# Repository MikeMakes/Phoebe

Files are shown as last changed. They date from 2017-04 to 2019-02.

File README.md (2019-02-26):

# Phoebe
I am Phoebe, an amphibian vehicle developed by students from the University of Seville.

The concept is a tele-operated airboat like vehicle with a raspberry pi as brain controled from a pc through Ad-Hoc wifi.

This was an one trimester class project that is alredy finished and abandoned but what you see is functional and there are somethings that even work well. 100% FREE SOFTWARE take whatever u want; if you do so, I would apreciatte a link to your project just for the sake of curiosity.

A full in detail doc (in spanish) can be found as doc.pdf.

# Adhoc

# Control

# Arducontrol

# All this is free

    Copyright (C) 2017
        Authors:
            * Miguel López Gil
            * Pelayo Gutiérrez Jiménez
            * Juan Sandubete López
            * Javier Ponce Chulani
            * Alvaro Morales Marquez
            * Bryan Kevin Condor Romero
            * Jose Manuel Salvador Vazquez

    This program is free software: you can redistribute it and/or modify
    it under the terms of the GNU General Public License as published by
    the Free Software Foundation, either version 3 of the License, or
    (at your option) any later version.

    This program is distributed in the hope that it will be useful,
    but WITHOUT ANY WARRANTY; without even the implied warranty of
    MERCHANTABILITY or FITNESS FOR A PARTICULAR PURPOSE.  See the
    GNU General Public License for more details.

    You should have received a copy of the GNU General Public License
    along with this program. If not, see <http://www.gnu.org/licenses/>.

# TODOs
* Finish readme
* Link doc.pdf

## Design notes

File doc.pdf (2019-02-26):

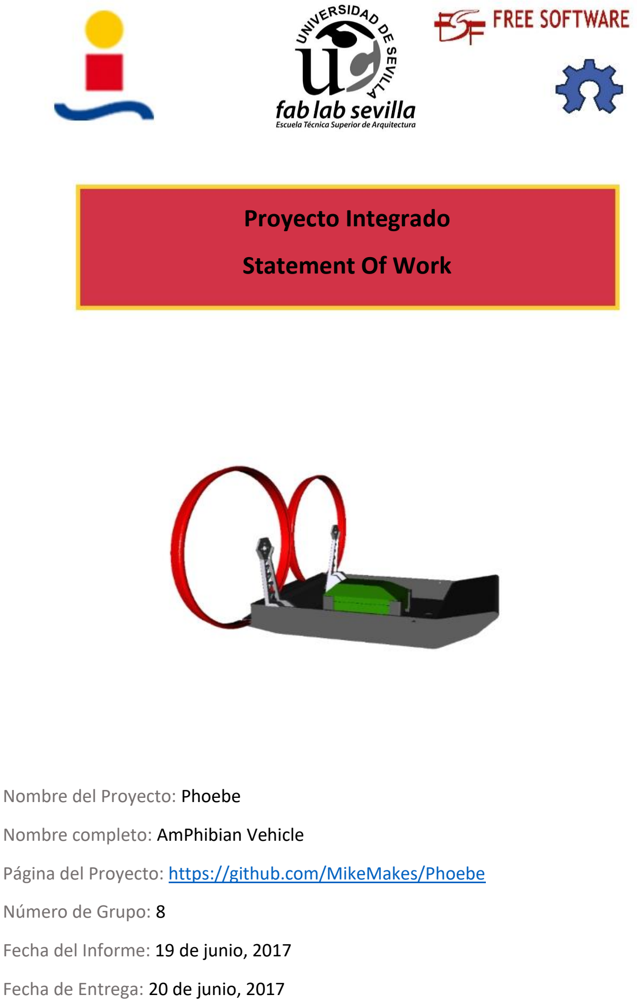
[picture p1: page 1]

Nombre del Proyecto: Phoebe

Nombre completo: AmPhibian Vehicle

Página del Proyecto: https://github.com/MikeMakes/Phoebe

Número de Grupo: 8

Fecha del Informe: 19 de junio, 2017

Fecha de Entrega: 20 de junio, 2017

## Proyecto Integrado

## Statement Of Work

## Índice

### Integrantes del Grupo

Bryan Kevin Cóndor Romero

Pelayo Gutiérrez Jiménez

Álvaro Morales Márquez

Javier Ponce Chulani

José Manuel Salvador Vázquez

Juan Sandubete López

3º GIERM

### 1. Introducción

El proyecto persigue desarrollar un vehículo radio-control anfibio multipropósito con retransmisión de vídeo en directo, a fin de expandir los conocimientos aplicados actualmente a UAVs (como son la electrónica de potencia, la ingeniería de control, la informática y otras) a otra clase de vehículos no tripulados poco estudiados hasta la fecha y proponerlo como solución a diferentes problemas.

Entre los sistemas que han sido desarrollados actualmente con la misma finalidad, se pueden encontrar diferentes proyectos que incluyen colchón aéreo; el conocido Hovercraft[1][2]
Aunque esto tiene claras ventajas sobre la fricción del vehículo con el terreno, supone incluir otro motor dedicado exclusivamente a generar dicho colchón de suspensión, que además de encarecer el precio del sistema, da lugar a una dependencia crucial entre la alimentación de dicho motor (y su correcto funcionamiento) y la integridad del sistema (que podría sumergirse en caso de no funcionar adecuadamente la suspensión aérea); por no contar con el hecho de que aumentaría considerablemente el consumo energético del vehículo, reduciendo la autonomía máxima alcanzable.

Como alternativa a la anterior opción, más cara y menos segura, se propone en el documento presente un vehículo anfibio en el que el colchón aéreo se sustituye por una barcaza estanca, para asegurar la flotabilidad del sistema. Una de las principales ventajas del diseño radica en la versatilidad del mismo; pues dicha superficie puede deslizar sin problemas por gran variedad de superficies, excluyendo, únicamente, superficies demasiado abrasivas como terrenos pedregosos.

Muchos son los posibles usos que se le pueden dar a este vehículo no tripulado. Algunas de las aplicaciones propuestas son:

- Supervisión de infraestructuras marítimas de difícil acceso o cuyo acceso conlleve peligro para las personas encargadas de su mantenimiento. Por ejemplo, supervisión del estado de la estructura inferior de un muelle o bien, la supervisión de cualquier tipo de estructuras situadas en zonas de aguas contaminadas[3]
- Vigilancia teleguiada de entornos nevados, pues la barcaza permite, primero, permanecer en estado de reposo durante más tiempo que un UAV tradicional, conservando energía, y segundo, la carencia de ruedas lo hace ideal para desplazarse por nieve.
- Visualización a distancia de zonas afectadas por inundaciones, preservando la seguridad del teleoperador. La naturaleza de la barcaza, permite que ésta se desplace, indistintamente, sobre terreno sólido, charcos o zonas inundadas. Además, la lluvia y el viento no son factores tan críticos como pudieran serlo para los UAV tradicionales.

### 2. Alcance

El sistema, como vehículo anfibio manejado por radio-control, debe ser capaz de desplazarse tanto por agua como por terreno sólido, pudiendo hacer la transición, al menos, de tierra al agua descendiendo una rampa de inclinación reducida. Además, transmitirá video por telemetría a una estación de monitorización y control; que dispone de un monitor donde se puede observar la visión proporcionada por el vehículo y envía las órdenes de control mediante comandos, a través de un Gamepad.

### 2.1 Memoria

El desarrollo del proyecto ha sido satisfactorio, no obstante, no pudieron alcanzarse todos los objetivos planteados.

La problemática comenzó la compra de los componentes. Al ser componentes caros, de aeromodelismo la mayoría de ellos, se optó por pedirlos de China y Taiwán, que los ofrecían a precios menores, aunque con mayor tardanza en la entrega.

Como consecuencia, en las dos primeras sesiones prácticas, sólo se pudo trabajar en el código que se pretendía emplear (Ad-hoc, TCP, streaming) y en la elaboración del circuito para la detección de agua; a la vez que se iba desarrollando la barcaza mediante diseño 3D.

Parte de los componentes llegaron, concretamente, los motores y las hélices; pero los controladores fueron pedidos incompatibles con los motores brushless empleados (pues eran para motores brushed); por lo que hubo que descambiarlos y se tardó más en recibir los nuevos controladores.

Para la cuarta sesión práctica ya se tenían tanto los controladores como los motores (además de parte de la estructura elaborada). Se pudieron probar los motores y controladores satisfactoriamente, aunque ya ahí se vio que no era fácil utilizar el protocolo de comunicación que emplean los controladores mediante la Raspberry.

En una de las sesiones prácticas que se hicieron adicionales (en un domicilio particular), se consideró que ya se podía probar el sistema completo, pues ya habían sido probados todos los subsistemas individualmente. Así pues, mientras se estaba procediendo con la calibración del segundo controlador, hubo un falló y en lugar de calibrarse, el controlador lo detectó como una activación. El fallo provocó una sobreintensidad que atravesó al controlador y lo quemó a tres días de la presentación final.

Como medida, se optó por emplear controladores de segunda mano, pero con mayor capacidad de control de corriente (pasando de los 10A a los 20A).

No obstante, los nuevos controladores no permitían la comunicación para los niveles de tensión maneja la Raspberry (3.4V respecto a los 5V necesarios). Por tanto, se pensó en diseñar una interfaz de comunicación entre la misma y los controladores.

Ésta se diseñó mediante dos transistores BJT en conexión Darlington, con una alimentación de 5V. Aunque por falta de tiempo (día previo a la presentación), se tuvo que optar, finalmente, por emplear como adaptador un Arduino en lugar de fabricar la placa de interfaz.

En los días siguientes a la presentación, se ha estado trabajando en la adaptación de la barcaza al medio acuoso. Con el fin de impermeabilizar la barcaza, se ha usado una resina de poliéster capaz de impregnar las piezas impresas en 3D. De este modo, se sellan las juntas y se consigue una mejor unión entre las diferentes secciones.

Además de la resina, para adquirir mayor robustez en toda la barcaza aplicamos una capa de fibra de vidrio en el casco, consiguiendo así una capa más de protección ante el rozamiento con el suelo.

Sin embargo, la fibra de vidrio ha creado burbujas en la capa de resina (imposibles de purgar en la práctica) por las que el agua puede fluir y alcanzar las capas más externas de la impresión 3D. Esto provoca unas pequeñas fugas en el casco que a largo plazo inundan la barcaza.

Por tanto, para el día de entrega de los resultados, se han tenido que abandonar los requisitos asociados a la desenvoltura del sistema en agua. Aunque algunos de las pruebas han podido ser realizadas (ver matriz de verificación), ninguna de las relacionadas al agua ha podido cumplirse satisfactoriamente.

No obstante, se ha conseguido (como se ve más fácilmente en la matriz de verificación) alcanzar objetivos que también fueron motivos de duda, como si iba a ser posible desplazar la barcaza por el suelo, únicamente con propulsión aérea; sobrepasándolos con creces.

También se ha conseguido realizar un streaming con una latencia muy baja y el control a distancia ha sido, también, superado. Aunque queda pendiente la aplicación de un control que sea de verdad útil para las aplicaciones que se describen en la introducción.

Por último, a pesar de que no ha sido probado, la potencia de la propulsión parece ser capaz de cumplir con los requisitos de transición de agua a tierra; quedando únicamente pendiente la estabilidad del control ya nombrada.

Los cambios realizados han sido, principalmente, el uso de una cámara USB en lugar de la CamPi, pues ésta parece que falló por alguna descarga electroestática, la adquisición de unos controladores más potentes de los que se compraron al principio y el empleo, temporal, de un Arduino como interfaz entre la Raspberry y los controladores.

Resumidamente, se ha conseguido que el sistema se desplace, que gire, que transmita vídeo en directo, que sea controlado a distancia (todo ello, dentro de los márgenes de tiempo deseado), que el sistema sea estable estática y dinámicamente en terreno sólido y que el sistema flote, siempre y cuando no se cargue con peso. Por otra parte, no se ha conseguido que el sistema se desplace por agua, ni, por tanto, se ha podido comprobar si era estable en dicho medio. Tampoco se ha conseguido realizar el control deseado del vehículo.

Puesto que el grupo pretende seguir con el trabajo adelante, creemos que alcanzaremos e incluso superaremos los objetivos planteados en este documento.

### 2.2 Requisitos

F.1. El sistema debe ser capaz de transmitir vídeo inalámbricamente a la estación de control.

P.1.1. El tiempo de retraso entre lo captado por la cámara en un determinado instante y el
| instante en el que es reproducido en el monitor de control no debe superar los 500ms.
F.2. | El sistema debe ser capaz de recibir órdenes inalámbricamente.

P.2.1. El tiempo de transmisión de las órdenes no debería ser superior a 50ms.

F.3. | El sistema debe ser capaz de ejecutar las acciones asociadas a las órdenes recibidas.
F.4. | El sistema debe ser capaz de desplazarse sobre el medio sólido liso.

P.4.1. El sistema debe ser capaz de desplazarse hacia adelante.

P.4.2. El sistema debe ser capaz de girar hacia la izquierda.

P.4.3. El sistema debe ser capaz de girar hacia la derecha.

F.5. El sistema debe ser capaz de desplazarse sobre el medio acuoso.

P.5.1. El sistema debe ser capaz de desplazarse hacia adelante.

P.5.2. El sistema debe ser capaz de girar hacia la izquierda.

P.5.3. El sistema debe ser capaz de girar hacia la derecha.

F.6. El sistema debe ser capaz de realizar la transición del medio sólido liso al medio acuoso.

P.6.1. La transición debe realizarse correctamente con una inclinación de, al menos, 15º.

F.7. El sistema podría ser capaz de realizar la transición del medio acuoso al medio sólido liso.

P.7.1. La transición podría realizarse correctamente con una inclinación de, al menos, 10º.

F.8. | El sistema debe ser capaz de detectar si se encuentra en medio acuoso o sólido.
F.9. | El sistema debe ser capaz de conmutar del modo de control para medio acuoso al modo de control para medio sólido.
D.1. | El sistema debe ser capaz de flotar en el agua.
D.2. | El sistema debe asegurar la estanqueidad de la cavidad principal interior¹ .
D.3. | El sistema debe asegurar la estanqueidad de la cavidad secundaria² .
D.4. | El sistema debe ser estable (equilibrado) en estado de reposo sobre el agua.
D.5. | El sistema debe ser estable (equilibrado) en movimiento sobre el agua.
D.6. | El sistema debe ser estable (equilibrado) en estado de reposo sobre terreno sólido liso.
D.7. | El sistema debe ser estable (equilibrado) en movimiento sobre terreno sólido liso.
C.1. | Presupuesto máximo del proyecto: 70€.
C.2. | El proyecto debe dar uso de una Raspberry Pi Model 3B.
C.3. | El tiempo de prueba de la Raspberry Pi Model B+ junto con la cámara es limitado (aproximadamente cuatro sesiones de 2h).

Notas:

1 Compartimento donde se transportan las baterías.

2 Compartimento donde se transportan los circuitos electrónicos.

### 2.3 WBS

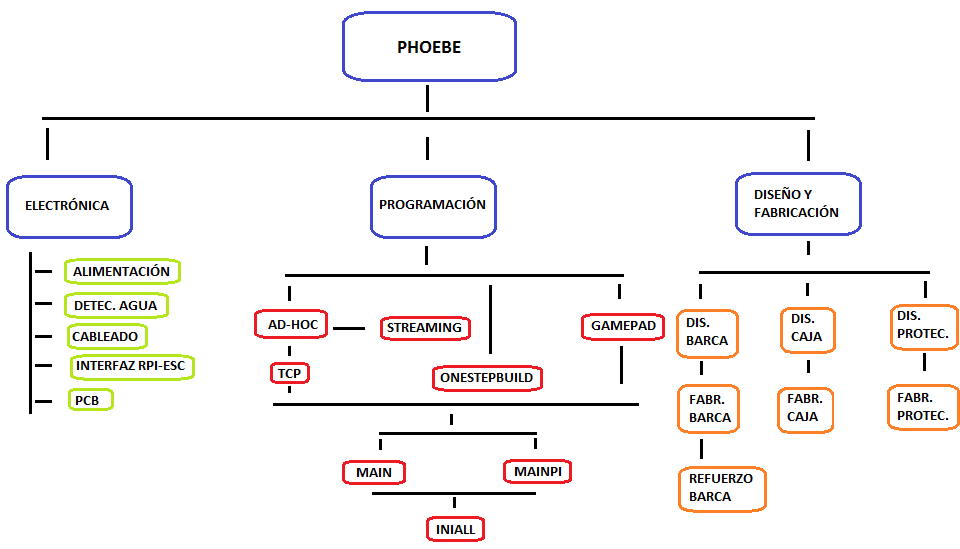
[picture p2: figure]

### 2.4 Descripción de Subsistemas

Electrónica:

- Alimentación: Sistemas de potencia del vehículo. Baterías, reguladores y controladores.
- Detección de agua: Sistema de detección de agua.
- Cableado: Cables de especificaciones adecuadas para cada subsistema.
- Interfaz Raspberry Pi – Controlador: Adaptación de la señal de la Raspberry a los valores exigidos por los controladores.
- PCB: Placa de conexionado para Raspberry, sensores, reguladores y controladores.

Programación:

- Ad-Hoc: Conexión nodal entre ordenador y Raspberry.
- Streaming: Transmisión de vídeo en directo.
- TCP: Conexión fiable entre ordenador y Raspberry sobre Ad-hoc.
- One Step Build: Instalación automática de todos los programas, ficheros y librerías necesarias para el funcionamiento del sistema al completo, en un solo click.
- Gamepad: Librería para la comunicación entre el ordenador y el gamepad (mando de control).
- Main: Programa a ejecutar en el ordenador para orquestar el monitoreamiento.
- Mainpi: Programa a ejecutar por la Raspberry para manejar todos los otros subsistemas asociados a ella.
- IniAll: Programa que detecta, automáticamente, el terminal en el que se está corriendo y ejecuta los subprogramas necesarios para el funcionamiento del sistema completo.

Diseño y Fabricación:

- Diseño x: Diseño de la estructura determinada mediante la herramienta de software libre FreeCAD.
- Fabricación Barca: Impresión 3D de las piezas que la componen.
- Fabricación Caja: Está por determinar el modo de fabricación.
- Fabricación Protecciones: Cortado láser de las protecciones que rodean a las hélices.
- Refuerzo Barca: Aplicación de resina y fibra de vidrio para impermeabilizar y dotar de resistencia a la estructura impresa.

### 3. Análisis de riesgo

RIESGO | SEVERIDAD | PROBABILIDAD | MEDIDA
Cortocircuito por inundación o salpicadura de agua en los motores. | Alta | Media | -Duplicar compra de motores. -Hacer pruebas con un sistema de suspensión externo al vehículo para evitar su hundimiento. -Colocar, estratégicamente, material para la succión de agua.
Incompatibilidad de componentes adquiridos. | Alta | Baja | -Investigar profundamente los componentes antes de su compra. -Dejar margen de presupuesto para errores. -Comprar componentes únicamente a tiendas que permitan su devolución.
Cortocircuito por inundación o salpicadura de agua en electrónica de control. | Alta | Media | -Diseñar el compartimento herméticamente y someterlo a prueba previa colocación de electrónica. -Colocar, estratégicamente, material para la succión de agua.
Sobreintensidad en los controladores | Alta | Alta | -Emplear fusibles que eviten la destrucción de los controladores. -Comprar controladores que manejen intensidades superiores a las exigidas por los motores.
Sobreintensidad en los motores. | Media | Media | -Revisión exhaustiva, por diferentes personas, del código a implementar, acotando fuertemente los valores máximos de pwm.
Inundación o salpicadura de la cámara de adquisición de video. | Media | Alta | -Colocar funda de aislamiento al periférico. -Situar la cámara en un lugar elevado de la estructura.
Rotura de la cámara por cargas electroestáticas. | Media | Media | -Manejar la cámara con cuidado. -Dejar margen en el presupuesto para la compra de una cámara web, al menos, de mala calidad.
Lesión (corte o contusión) debida a las hélices. | Alta | Media | -Una persona supervisará y sostendrá el vehículo con guantes de trabajo para cada prueba. -Protocolo de seguridad: no se arranca el motor hasta que todos estén preparados para la prueba.
Fugas de agua dentro de la barcaza durante las pruebas de estanqueidad. | Baja | Alta | -Grabar todo el proceso para identificar la localización de la fisura. Añadir material en la zona afectada.

Inundación del compartimento de la batería (casco del vehículo). | Alta | Baja | -Comprobar estanqueidad del compartimento previamente a cada prueba. -Colocar funda de aislamiento para la batería.
Insuficiencia de propulsión para desplazarse en medio acuoso. | Media | Baja | -Estimar fuerzas viscosas y fuerzas de propulsión previa compra de sistema de impulso. -Si falla una vez comprado, aumentar la superficie del vehículo, disminuyendo el área frontal sumergida³ .

3Disminuyendo así las fuerzas viscosas que se oponen al desplazamiento.

### 4. Criterios de Aceptación

### 4.2 Matriz de Verificación

Requisito | Nombre del Requisito | Verificación |I|A|D|T|⁴ | Nombre de Prueba | Estado
F.1. | Transmisión inalámbrica de vídeo. | D | Demostración 1 | Ok
P.1.1. | Retraso máximo en transmisión de vídeo. | A | Análisis 1 | Ok
F.2. | Recepción de órdenes inalámbricamente. | T | Test 1 | Ok
P.2.1. | El tiempo de transmisión de las órdenes máximo. | A | Análisis 2 | Ok
F.3. | Ejecución de órdenes recibidas. | D | Demostración 2 | Mejorar
F.4. | Desplazamiento sobre medio sólido-liso. | D | Demostración 3 | Ok
P.4.1. | Desplazamiento frontal. | D | Demostración 4 | Ok
P.4.2. | Giro a la izquierda. | D | Demostración 5 | Ok
P.4.3. | Giro a la derecha. | D | Demostración 6 | Ok
F.5. | Desplazamiento sobre medio acuoso. | D | Demostración 7 | Pdte.
P.5.1. | Desplazamiento frontal. | D | Demostración 8 | Pdte.
P.5.2. | Giro a la izquierda. | D | Demostración 9 | Pdte.
P.5.3. | Giro a la derecha. | D | Demostración 10 | Pdte.
F.6. | Transición del medio sólido liso al medio acuoso. | D | Demostración 11 | Pdte.
P.6.1. | Inclinación mínima. | T | Test 2 | Pdte.
F.7. | Transición del medio acuoso al medio sólido liso. | D | Demostración 12 | Pdte.
P.7.1. | Inclinación mínima. | T | Test 3 | Pdte.
F.8. | Detección automática del medio. | T | Test 4 | Ok
F.9. | Conmutación automática de modo de control. | T, D | Test 5, Demostración 13 | Pdte.
D.1. | Flotabilidad. | D | Demostración 14 | Mejorar
D.2. | Estanqueidad principal. | D | Demostración 15 | Mejorar
D.3. | Estanqueidad secundaria. | D | Demostración 16 | Pdte.
D.4.-D.6. | Estabilidad asegurada por equilibrio de fuerzas y momentos, estático. | I, A | Inspección 1, Análisis 3 | No completa.
D.5.-D.7. | Estabilidad asegurada por equilibrio de fuerzas y momentos, dinámico. | I, A | Inspección 2, Análisis 4 | No completa.

4
I, A, D, T: Inspección, Análisis, Demostración, Test.

### 4.3 Plan de Pruebas

Nombre de Prueba | Demostración 1
Lugar | ETSI
Objeto de verificación | Cámara y software de vídeo.
Fecha | 1-06-2017
Detalles de la prueba | Se pondrá el objeto de verificación en funcionamiento (conjunto cámara-Raspberry) se comprobará que transmita adecuadamente el vídeo.
Realización | Sí.
Comentarios | El Streaming funciona adecuadamente empleando ffmpeg en transmisión directa; no obstante, se experimenta una latencia notable (>1s) cuando se ejecuta el lado del cliente por primera vez. Ésto parece solucionarse al reiniciar el lado del cliente. Quizás esté relacionado con la estructura del búfer.
Nombre de Prueba | Demostración 2
Lugar | ETSI
Objeto de verificación | Sistema completo.
Fecha | 1-06-2017
Detalles de la prueba | Se pondrá el objeto de verificación en funcionamiento y se comprobará que comporte como se le pide mediante comandos.
Realización | Sí.
Comentarios | El control empleado en las pruebas era demasiado rudimentario, por tanto, la dinámica exponencial de los motores hizo casi imposible el control de los mismos. Un controlador logarítmico ha sido desarrollado, aunque aún no se ha probado.
Nombre de Prueba | Demostración 3, 4, 5, 6
Lugar | Domicilio particular
Objeto de verificación | Sistema completo.
Fechas | 3, 4, 5, 6: 5-06-2017.
Detalles de la prueba | Se pondrá el objeto de verificación en funcionamiento y se comprobará que cumpla adecuadamente los requisitos asociados.
Realización | Sí.
Comentarios | No se pudo observar todo el potencial del vehículo pues las pruebas se realizaron en un entorno limitado de espacio.

Nombre de Prueba | Demostración 7, 8, 9, 10
Lugar | Domicilio Particular
Objeto de verificación | Sistema completo.
Fechas | 7, 8, 9, 10: 18-06-2017.
Detalles de la prueba | Se pondrá el objeto de verificación en funcionamiento y se comprobará que cumpla adecuadamente los requisitos asociados. Las pruebas 7, 8, 9, 10 se realizarán colocando hilos de seguridad, a modo de arnés, al vehículo; a fin de reducir el riesgo de hundimiento.
Realización | No.
Comentarios | Estas demostraciones dependen de D.1, D.2 y D.3, las cuales aún no han sido probadas satisfactoriamente. Las demostraciones quedan a la espera de la solución de los problemas de estanqueidad.
Nombre de Prueba | Demostración 11
Lugar | ETSI
Objeto de verificación | Sistema completo.
Fechas
Detalles de la prueba | Se empleará una pequeña piscina hinchable, proporcionada por FabLab de arquitectura, junto con una plancha, de cualquier material liso, haciendo experimentos de descenso con diferentes inclinaciones de la plancha.
Realización | No.
Comentarios | Deben solucionarse los problemas de D.1, D.2 y D.3 previamente.
Nombre de Prueba | Demostración 12
Lugar | ETSI
Objeto de verificación | Sistema completo.
Detalles de la prueba | Se empleará una pequeña piscina hinchable, proporcionada por FabLab de arquitectura, junto con una plancha, de cualquier material liso, haciendo experimentos de ascenso con diferentes inclinaciones de la plancha.
Realización | No.
Comentarios | Deben solucionarse los problemas de D.1, D.2 y D.3 previamente.

Nombre de Prueba | Demostración 13
Lugar | Fablab
Objeto de verificación | Código de detección de agua y conmutación de control
Detalles de la prueba | Se colocará el vehículo en el medio sólido y se monitoreará el modo de control activado en el mismo. Con el sistema aún encendido, se llevará éste al medio acuoso y se monitoreará el modo de control activado. Para el monitoreamiento del modo de control, de manera sencilla, pueden asociarse unos leds que lo indiquen.
Realización | No.
Comentarios | Aún no se ha podido comprobar debido a la fuga de agua. Del mismo modo, falta desarrollar el control para el medio acuoso y el código asociado a la conmutación automática del modo de control.
Nombre de Prueba | Demostración 14
Lugar | Domicilio particular.
Objeto de verificación | Barcaza
Fecha | 18-06-2017
Detalles de la prueba | Se colocará la barcaza en un recipiente lo suficientemente grande con agua. Se irá incrementando paulatinamente el peso sobre la misma hasta que llegue al límite antes de inundarse. Se anotará el peso máximo.
Realización | Sí.
Comentarios | La barcaza flotó adecuadamente sin peso colocado sobre la misma. No obstante, al colocársele un peso de, aproximadamente, 400g, una de las paredes, afectada por un choque, cedió parcialmente, dando lugar a una fuga de agua.

Nombre de Prueba | Demostración 15
Lugar | Domicilio particular
Objeto de verificación | Barcaza
Fecha
Detalles de la prueba | Se probará que la barcaza es estanca colocándola de diferentes formas en el agua (base hacia arriba, base de lado, etc.). Se comprobará que no haya agua en el interior tras cada posición, repitiéndolas para diferentes pesos.
Realización | No.
Comentarios | Aún falta solucionar la fuga de agua.
Nombre de Prueba | Demostración 16
Lugar | Domicilio particular
Objeto de verificación | Caja interior de la barcaza
Detalles de la prueba | Se volverá a realizar la demostración 15 pero con objeto de verificación distinto.
Realización | No.
Comentarios | Se están pensando diferentes materiales para la elaboración de la caja, ya que la impresión 3D ha parecido no ser una buena opción para evitar fugas, o no, al menos, mediante el método empleado.
Nombre de Prueba | Inspección 1
Lugar | Apartamento particular.
Objeto de verificación | Sistema completo
Fecha | 18-06-2017
Detalles de la prueba | Se le pondrán varios hilos al vehículo, por seguridad, del que penderá en caso de no funcionar adecuadamente. El vehículo se colocará sobre el medio acuoso y se comprobará que sea estable sin perturbaciones. Luego se hará lo mismo en medio sólido liso.
Realizado | Sí.
Comentarios | Aunque se han realizado estas inspecciones, sólo ha sido satisfactoria la relacionada al medio sólido liso. En el medio acuoso falla debido a una fuga de agua ya localizada.

Nombre de Prueba | Inspección 2
Lugar | Apartamento particular.
Objeto de verificación | Estabilidad dinámica.
Fecha | 5-06-2017
Detalles de la prueba | Se le pondrán varios hilos al vehículo, por seguridad, del que penderá en caso de no funcionar adecuadamente. El vehículo se colocará sobre medio acuoso y se comprobará que sea estable al desplazarse a mitad de su velocidad máxima. Luego se hará lo mismo en medio sólido liso.
Realización | No completamente.
Comentarios | La estabilidad dinámica del vehículo en medio sólido liso es muy buena. En el medio acuoso no se ha podido comprobar debido a la fuga de agua.
Nombre de Prueba | Test 1
Lugar | Domicilio particular.
Objeto de verificación | Recepción de órdenes
Fecha | 16-05-2017
Detalles de la prueba | Se comprobará la conexión establecida entre el centro de monitoreamiento (un ordenador personal) y la Raspberry haciendo ping tras ejecutar el código de la conexión TCP. Luego se comprobará la recepción adecuada del valor de los comandos (gatillo izquierdo o gatillo derecho) introducidos mediante el Gamepad.
Realización | Sí.
Comentarios | Hubo que hacer varias modificaciones en el código de conexión TCP para que el receptor, Raspberry, tomara por separado los valores del gatillo y la identificación del gatillo (Right o Left).
Nombre de Prueba | Test 2
Lugar | Fablab
Objeto de verificación | Inclinación mínima sólido-acuoso
Fecha
Detalles de la prueba | Se medirá qué inclinación mínima puede soportar el vehículo, durante una transición de bajada, de manera satisfactoria.
Realización | No.
Comentarios | Aún no se ha podido comprobar debido a la fuga de agua.

Nombre de Prueba | Test 3
Lugar | Fablab
Objeto de verificación | Inclinación mínima acuoso-sólido
Fecha
Detalles de la prueba | Se medirá qué inclinación mínima puede superar el vehículo, durante una transición de subida, de manera satisfactoria.
Realización | No.
Comentarios | Aún no se ha podido comprobar debido a la fuga de agua.
Nombre de Prueba | Test 4
Lugar | ETSI
Objeto de verificación | Detección automática de agua
Fecha | 16-05-2017
Detalles de la prueba | Se utilizará el circuito de detección de agua desarrollado, de manera simplificada, empleando un recipiente, que contendrá agua, donde se introducirán las partes sensibles del mismo.
Realización | Sí.
Comentarios | El test se realizó primero empleando la entrada analógica de un Arduino a fin de comprobar que se diera, efectivamente, un cambio de tensión al introducir las partes sensibles en el agua. Luego se contrastó, satisfactoriamente, con la Raspberry.
Nombre de Prueba | Test 5
Lugar | Domicilio particular
Objeto de verificación | Conmutación del modo de control
Fecha
Detalles de la prueba | Con la Raspberry conectada a un monitor, se comprobará del modo de control activado en la misma. Luego se mojarán los sensores de detección de agua y se comprobará el modo de control activado.
Realización | No.
Comentarios | Aún no se ha podido comprobar debido a la fuga de agua. Del mismo modo, falta desarrollar el control para el medio acuoso y el código asociado a la conmutación automática del modo de control.

Nombre de Prueba | Análisis 1
Lugar | Domicilio particular
Objeto de verificación | Transmisión de vídeo
Detalles de la prueba | Se comprueba que la retransmisión de vídeo sea menor a los 500ms. Para ello, se graba con una tercera cámara, simultáneamente, a un patrón de movimiento (como una mano moviéndose) y al vídeo retransmitido. Luego sólo hay que comprobar en la grabación de la tercera cámara el desfase entre una acción y otra.
Realización | Sí.
Comentarios | Se realizó tal y como indicaba la prueba sin ningún contratiempo.
Nombre de Prueba | Análisis 2
Lugar | Domicilio particular
Objeto de verificación | Transmisión de comandos
Detalles de la prueba | Se comprobará la latencia de transmisión de comandos mediante un ping (que devuelve un valor aproximado de la misma) entre ambas partes.
Realización | Sí.
Comentarios | La latencia está entorno a los 35ms, inferior al límite establecido de 50ms.
Nombre de Prueba | Análisis 3
Lugar | Domicilio particular
Objeto de verificación | Sistema completo
Detalles de la prueba | Se determina el centro de gravedad de la barcaza. Éste debe estar situado en una zona lo más centrada en la base como sea posible, pudiendo modificarse mediante la distribución adecuada de los pesos. Para ello, se coloca la barcaza en el borde, recto, de una superficie, como una mesa, perpendicular a dicho borde. Se va empujando hasta que ésta bascula. A esa recta, pertenecerá el centro de gravedad. Se repite el proceso con la barcaza en paralelo al borde y se obtiene el centro.
Realización | Sí.
Comentarios | Aunque la estabilidad estática está asegurada, la batería se ha colocado en la parte frontal para asegurar la estabilidad dinámica del sistema.

Nombre de Prueba | Análisis 4
Lugar | Domicilio particular
Objeto de verificación | Sistema completo
Detalles de la prueba | Se comprueba el torque generado por los motores empleando un peso (de cocina) y una estructura simple de madera elaborada para la prueba. Se estima la fuerza de empuje de Arquímedes que se opone al torque de los motores. Se comprueba que no se alcancen unos valores inadecuados para asegurar la integridad del sistema.
Realización | No.
Comentarios | No estamos muy convencidos de la metodología de esta prueba, pues el análisis, para ser útil, debería ser más complejo.

### 5. PROGRAMAS

La sección se organiza en base al orden establecido en el WBS.

### 5.1 ADHOC

-ahon.sh

Script en bash que configura la conexión AdHoc de forma automática y testea la conexión tanto en la Raspberry como en el portátil (GNU/Linux). También crea un backup de la configuración inalámbrica actual.

-ahoff.sh

Script en bash que restaura la configuración original del sistema y comprueba que funcione bien.

-interfaces.adhoc*

Archivos de configuración para la conexión AdHoc de la Raspberry y un sistema GNU/Linux.

### 5.2 STREAMING

-ffmpeg

Programa que sirve para grabar vídeo, codificarlo y procesarlo. Permite incluso el uso de más de mil filtros diferentes. Aquí se usa simplemente para enviar el vídeo tomado de la cámara web, codificarlo en formato mp4 mediante la librería h264 y enviarlo mediante UDP a la dirección escrita en el comando (dirección IP destino mediante Ad-Hoc).

-ffplay

Permite detectar el vídeo transmitido pasándole la dirección IP y el puerto desde el cual se emite el vídeo.

### 5.3 TCP

-tcp.py

Librería en python (realmente es un método) utilizada para configurar la conexión tcp tanto en el servidor como en el cliente. También se encarga de añadir caracteres de control en los mensajes enviados de recibirlos correctamente.

-server_example.py

Ejemplo de cómo utilizar tcp.py en el lado del servidor. Un servidor simple que re-envía al cliente una cadena de caracteres.

-client_example.py

Ejemplo de cómo utilizar tcp.py en el lado del cliente. Envía una cadena al servidor y espera una posible respuesta.

### 5.4 ONE STEP BUILD

-one-step_build.sh

Script en bash que comprueba que comprueba si todas las dependencias están instaladas e instala laas que no estén

### 5.5 GAMEPAD

-gamepad.py

Librería en python para obtener una entrada desde un mando de consola. Utiliza a su vez la librería de python ev-dev basada en programaxión dirigida por eventos. Esta librería es ejecutable, mostrando un pequeño ejemplo de cómo puede ser utilizada.

-ps3map.py

Mapea los botones de un mando Dualshock 3 de forma que el código sea más entendible para los humanos.

### 5.6 MAIN

-main.py

Este script se ejecuta en la Raspberry, y es un test para comprobar que la conexión TCP entre portátil y Raspberry es correcta y que la Raspberry recibe correctamente el valor mandado por el portátil.
La Raspberry crea una conexión TCP, con ella como servidor y espera a que el portátil se conecte. Una vez conectado, la Raspberry primero recibe el gatillo que ha cambiado su valor (RIGHT o LEFT), y luego el valor del gatillo que ha cambiado. Para tener la certeza de que se ha realizado correctamente, se imprime por pantalla el gatillo que ha cambiado, así como su valor.

### 5.7 MAINPI

-mainpi.py

Es un script que se ejecuta en la Raspberry. Recibe del portátil por conexión TCP el gatillo que ha cambiado de valor, así como el valor del mismo. La conexión TCP la inicia la Raspberry con esta como servidor, y espera a que se conecte el portátil. Para controlar los variadores, es necesario utilizar una señal PWM, por lo que el valor del gatillo se transforma en un valor apto para el PWM. Esto se realiza con la función "map" definida en el script. Inicialmente, el PWM es el mínimo para que los motores estén parados. Luego, cuando recibe información del portátil, cambia el valor del PWM del motor derecho si se ha enviado el valor del gatillo derecho, y del motor izquierdo si se ha enviado el valor del gatillo izquierdo. Estos valores se cambian con la función "map" para pasarlos a PWM y se asigna ese valor de PWM al motor correspondiente. En caso de que cualquier cosa falle (establecimiento de conexión, recepción de datos, lectura de datos) el script dejará de ejecutarse, poniendo el valor de los PWM al mínimo.
Se ha utilizado la librería "tcp" para la conexión TCP, y la librería "pwm" para el funcionamiento del PWM de la Raspberry.

### 5.8 INIALL

-iniall.sh

Este script es uno global que permitiría poner en funcionamiento la cámara por ffmpeg y el script mainpi.py, que se encarga de controlar los motores según el mando conectado en el portátil. Se contempla la posibilidad de dos modelos diferentes de Raspberry Pi, porque son los modelos con los que se han trabajado. Si el Ad-hoc está encencido, enciende primero la cámara y muestra el vídeo en el ordenador, y luego ejecuta mainpi.py. Si por el contrario está apagado, primero lo enciende y luego hace lo mismo de antes.

### 5.9 CONTROL

-control1.ino

El control se ha desarrollado en lenguaje de Arduino por los inconvenientes comentados en la memoria. En él, se hace una lectura analógica del PWM emitido por la Raspberry, que emite dos señales de PWM (una para cada motor), se hace una conversión para pasar de 1024 valores a 256, mediante la función map, y se transmite la señal al controlador de velocidad mediante las funciones de la librería servo.h, que permiten la comunicación con un protocolo medianamente estándar: SimonK (muy utilizado en controladores de velocidad).

Recalcar que ésta es una solución temporal, por ello no se ha incluido en el WBS.

### 6. PRESUPUESTO REAL

### 6.1. Diseño

Elemento | Precio (€)
Estructura impresa. | 7
Plástico termoformable (material). | 3
Tiempo de uso de maquinaría (Fablab). | 6
Total | 16 €

### 6.2. Electrónica

Elemento | Precio (€)
MPU (Acel. + Brújula) | 3’20
Batería (12V) | 9’80
Regulador (5V) | 1’5
4x Motor (+ Hélice + Anclaje) | 19’40
2x ESC10A + 2x ESC20A | 9+16
Total | 58,90 €

### 6.3 Presupuesto inicial:

Grupo | Presupuesto de Grupo (€)
Diseño | 16
Electrónica | 58’9
Total | 74,90 €

## 7. BIBLIOGRAFÍA

[1] Hovercraft: https://es.wikipedia.org/wiki/Aerodeslizador
[2] Handmade RC Hovercraft: http://www.instructables.com/id/How-to-make-a-RC-Hovercraft/ (http://www.instructables.com/id/How-to-make-a-RC-Hovercraft/)
[3] Aguas contaminadas de India: http://www.bbc.com/mundo/noticias/2014/07/140702_salud_ganges_riesgo_nadar_gtg

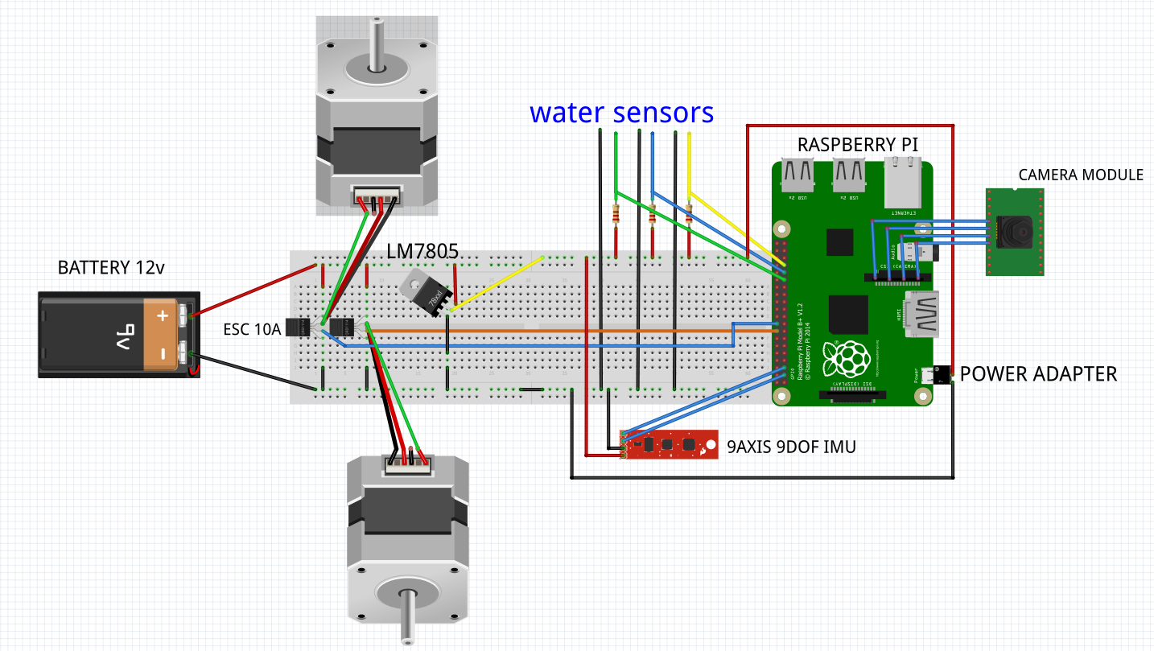
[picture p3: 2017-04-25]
Hardware/Electronic/protoboard.PNG

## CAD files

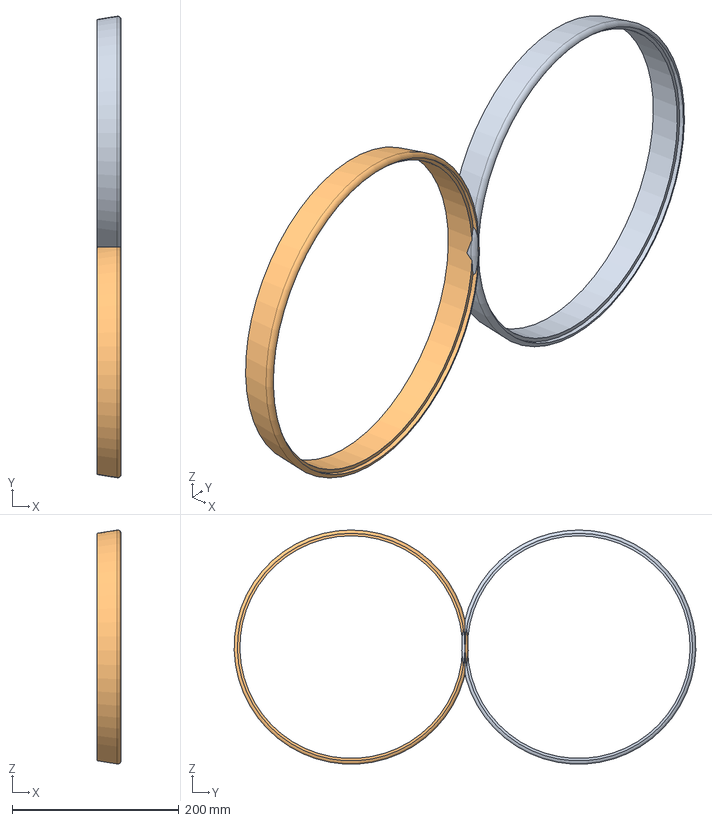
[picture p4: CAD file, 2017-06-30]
Hardware/Structure/Untitled.FCStd
29.0 x 553.8 x 280.7 mm
Revolution (Mirror #1)

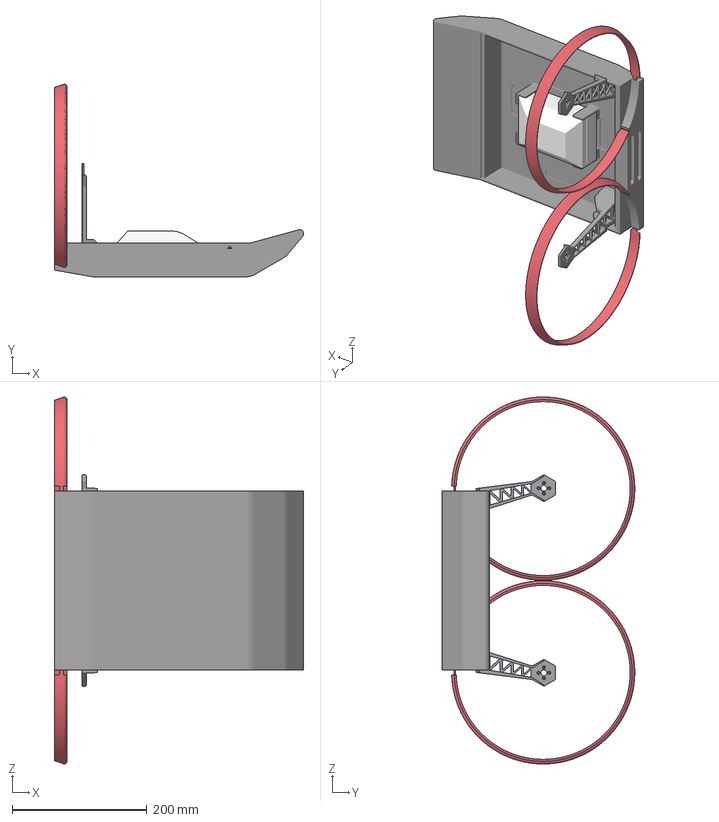
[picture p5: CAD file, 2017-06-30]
Hardware/Structure/asembly.FCStd
370.4 x 286.0 x 544.8 mm
hull_asembly
motor_mount
fancover montage
motor_mountR
raspbox

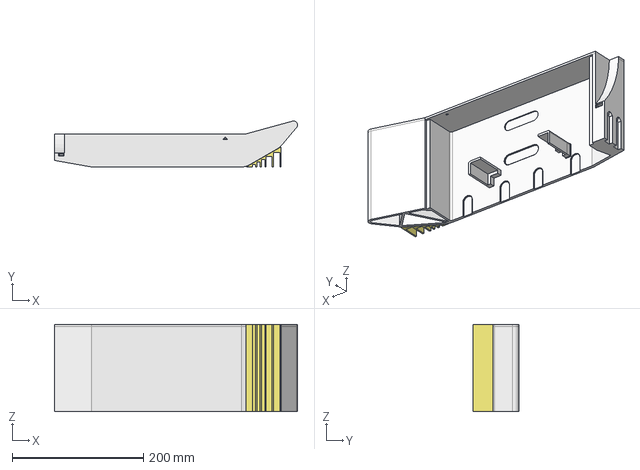
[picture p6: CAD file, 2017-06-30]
Hardware/Structure/Hull.FCStd
370.0 x 70.0 x 133.0 mm

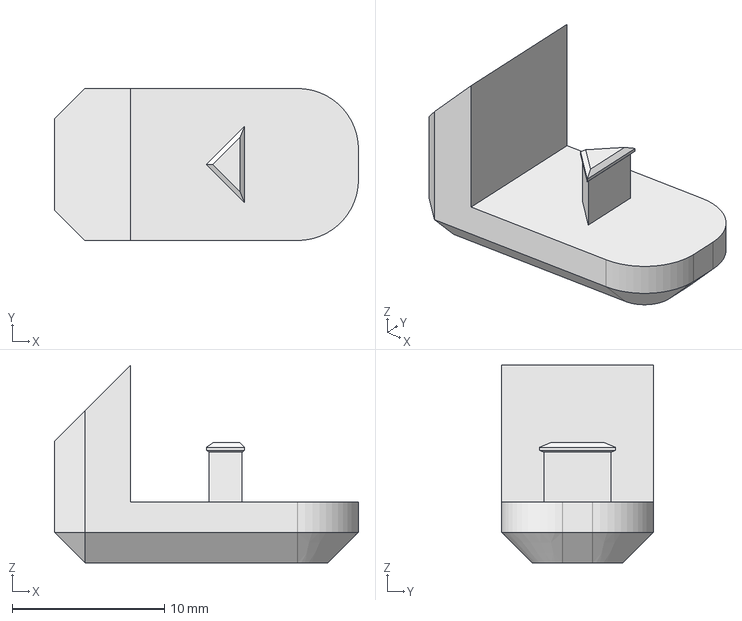
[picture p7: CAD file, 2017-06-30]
Hardware/Structure/clip.FCStd
20.0 x 10.0 x 13.0 mm

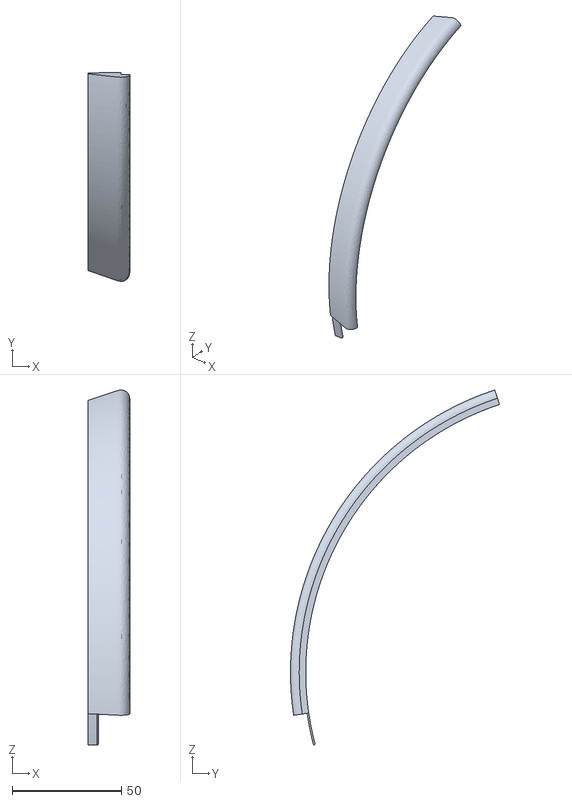
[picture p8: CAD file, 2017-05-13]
Hardware/Structure/fancover2.stl
19.0 x 95.7 x 162.5

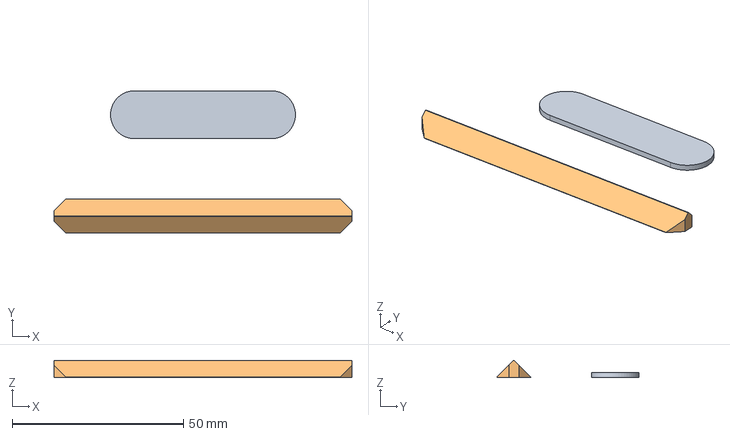
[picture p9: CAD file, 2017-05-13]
Hardware/Structure/joints.FCStd
87.0 x 41.6 x 5.00 mm

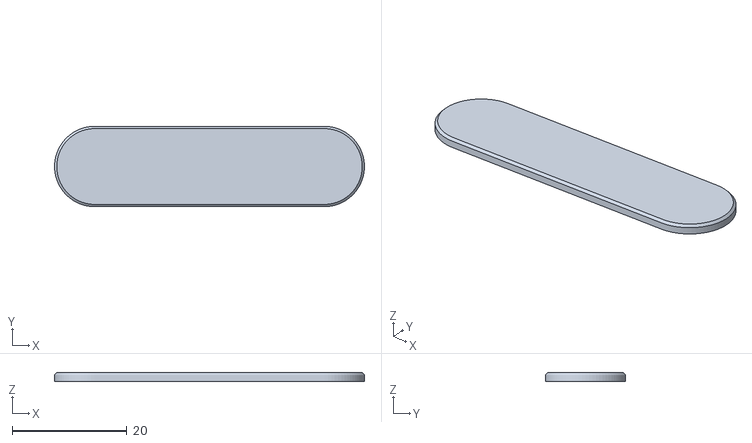
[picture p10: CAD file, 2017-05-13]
Hardware/Structure/joint_floor.stl
54.0 x 14.0 x 1.50

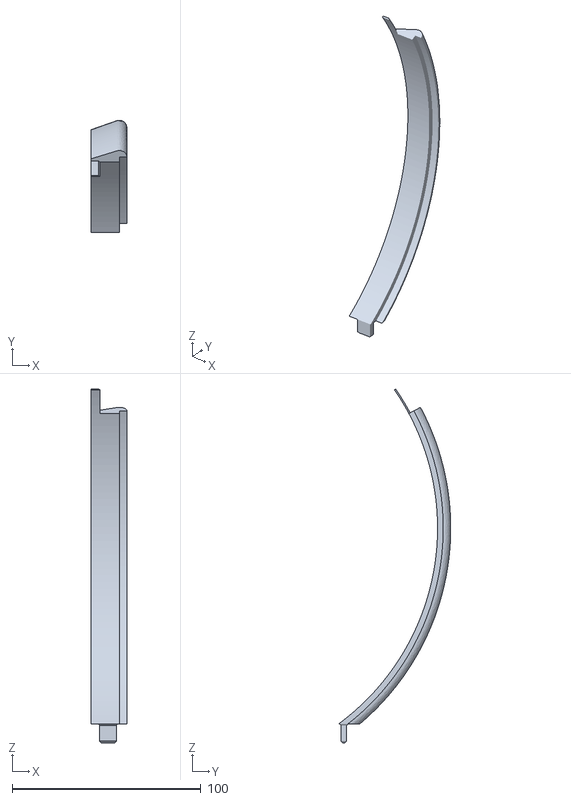
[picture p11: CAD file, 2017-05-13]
Hardware/Structure/fancover3.stl
19.0 x 59.7 x 187.8

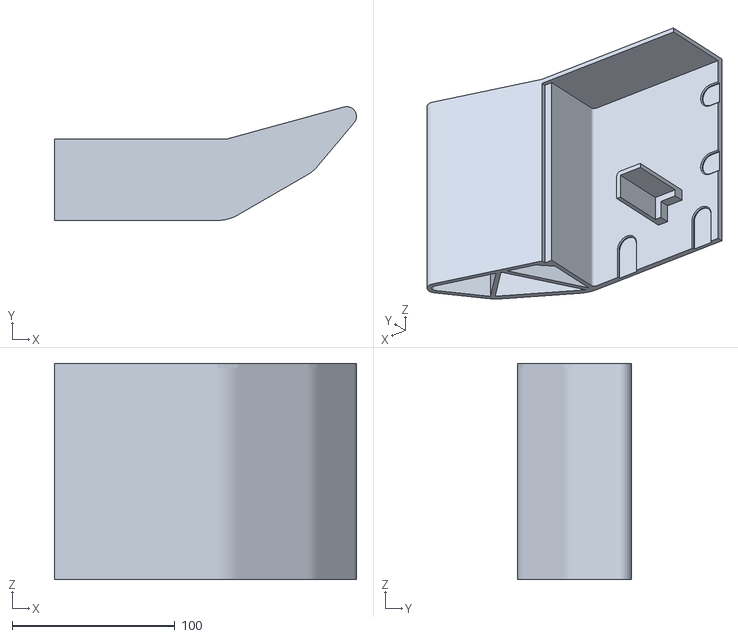
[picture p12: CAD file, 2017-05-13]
Hardware/Structure/hull_front.stl
185.7 x 70.0 x 133.0

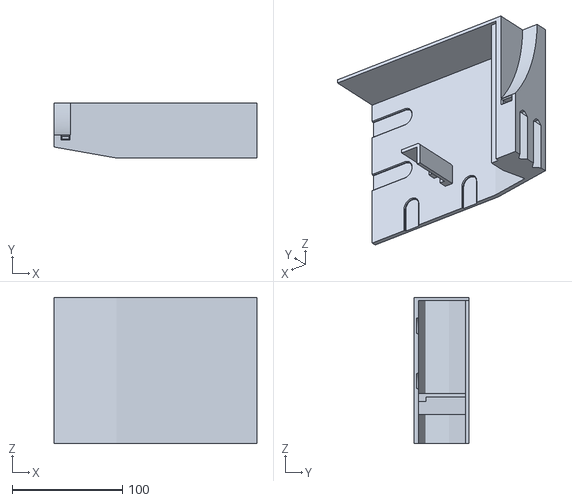
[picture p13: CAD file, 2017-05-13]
Hardware/Structure/hull_back.stl
184.3 x 50.0 x 133.0

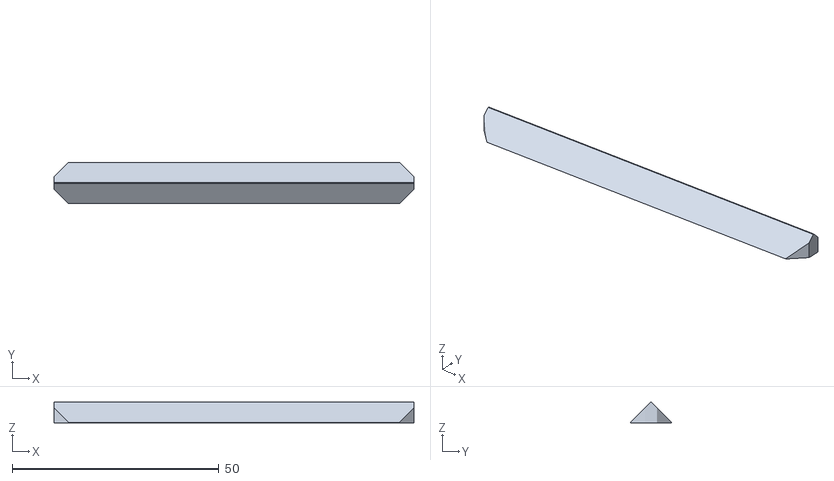
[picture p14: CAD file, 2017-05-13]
Hardware/Structure/joint_back.stl
87.0 x 10.0 x 5.00

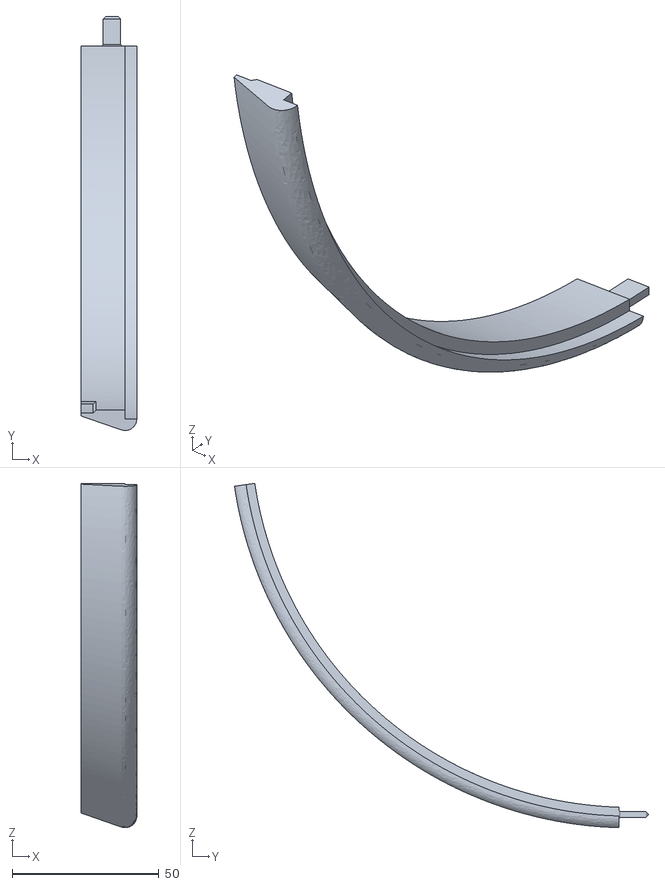
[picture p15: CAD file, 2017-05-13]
Hardware/Structure/fancover1.stl
19.0 x 140.9 x 117.2

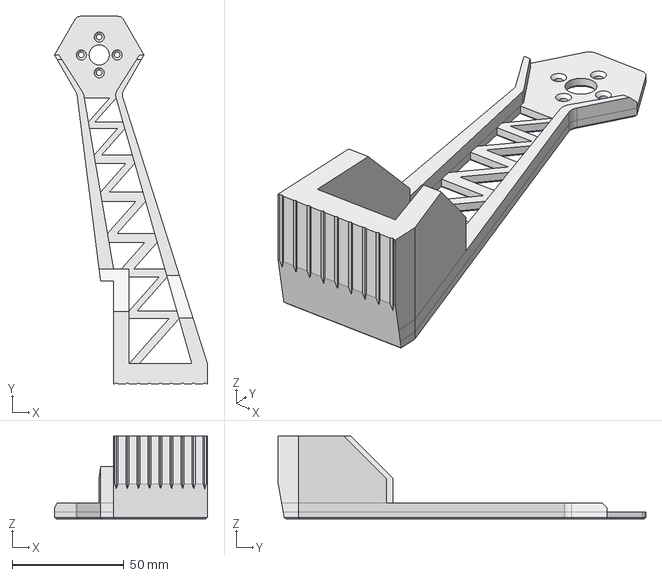
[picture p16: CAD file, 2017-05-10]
Hardware/Structure/motor_mount.FCStd
68.4 x 164.3 x 37.0 mm

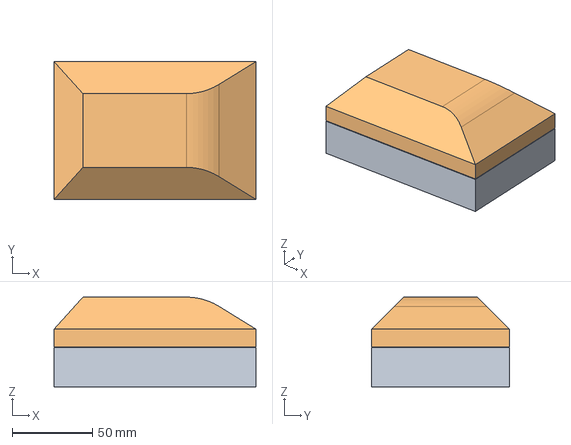
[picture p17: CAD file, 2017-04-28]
Hardware/Structure/raspbox.FCStd
126.0 x 86.0 x 56.0 mm

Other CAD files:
Hardware/Structure/cut_fan.FCStd
Hardware/Structure/fancover.FCStd
Hardware/Structure/Planos.dwg
Hardware/Structure/Planos1.dwg

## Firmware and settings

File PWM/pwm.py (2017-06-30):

import RPi.GPIO as GPIO
from time import sleep

GPIO.setmode(GPIO.BCM)

def __init__(pin=24,freq=480):
	GPIO.setup(pin, GPIO.OUT)
	return GPIO.PWM(pin, freq)

def start(pwm=None, dc=0):
	if pwm is None:
		return None     #Must be substituted for exception
	pwm.start(dc)

def changedc(pwm=None, dc=0):
	if pwm is None:
		return None     #Must be substituted for exception
	pwm.ChangeDutyCycle(dc)

def changefrew(pwm=None, freq=480):
	if pwm is None:
		return None     #Must be substituted for exception
	pwm.ChangeFrequency(freq)

def end(pwm=None):
	if pwm is None:
		return None     #Must be substituted for exception
	pwm.stop()

def clean():
	GPIO.cleanup()
	
if __name__ == "__main__" :
	pwm=__init__()
	start(pwm,0)
	for i in range(100):
		changedc(pwm,i)
		sleep(15)
	end(pwm)
	clean()
	

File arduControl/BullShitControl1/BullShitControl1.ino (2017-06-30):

#include <Servo.h>

int rm = A0;
int lm = A1;
int valueR, valueL;

Servo leftESC, rightESC;

void setup() {

  leftESC.attach(9);  // attached to pin 9 
  rightESC.attach(10); //attached to pn 10
}

void loop(){
 valueR = analogRead(rm);
 valueL = analogRead(lm);
 
 valueR=map(valueR,0,255,1000,2000);
 valueL=map(valueL,0,255,1000,2000);
 
 rightESC.writeMicroseconds(valueR);
 leftESC.writeMicroseconds(valueL);

 
  
}
  

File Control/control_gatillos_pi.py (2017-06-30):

from pwm import *
from tcp import *
GPIO.setmode(GPIO.BCM)
def map(bar, from_min=0,  from_max=255,  to_min=5,  to_max=10):
  return (bar - from_min) * (to_max - to_min) / (from_max - from_min) + to_min;

GPIO.setup(12, GPIO.OUT)
GPIO.setup(13, GPIO.OUT)

motor1 = GPIO.PWM(12, 50)
motor2 = GPIO.PWM(13, 50)

motor1.start(0)
motor2.start(0)

try:
	server = tcp.mysocket()
	server.server("192.168.1.192", 4200) #RPI IP
	server.accept

	exit = False

	while not exit:
		Input = server.recieve()
		if Input == "RIGHT":
			p_der = int(server.recieve())
			p_der = map(p_der)
			pwm.changedc(motor1, p_der)
		elif Input == "LEFT":
			p_izq = int(server.recieve())
			p_izq = map(p_izq)
			pwm.changedc(motor2, p_izq)
		elif Input == "EXIT":
			exit = True
finally:
	motor1.stop()
	motor2.stop()
	GPIO.cleanup()
	server.closesocket()
	clean()

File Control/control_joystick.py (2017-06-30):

import RPi.GPIO as GPIO
import gamepad
GPIO.setmode(GPIO.BCM)

GPIO.setup(12, GPIO.OUT)
GPIO.setup(13, GPIO.OUT)

motor1 = GPIO.PWM(12, 480)
motor2 = GPIO.PWM(13, 480)


motor1.start(0)
motor2.start(0)

try:

	while True:
		gamepad = search_devices('Sony PLAYSTATION(R)3 Controller')
		for event in gamepad.read_loop():
			direccion = axe_move(ljX_axe)
			p_in = axe_move(r2_axe)+128
			print ("Valor de R2:{}".format(direccion))
			print ("Valor de joystick izquierdo:{}".format(p_in))
			if direccion = 0:
				motor1.start(p_in)
				motor2.start(p_in)
			if direccion < 0:
				p_der = p_in
				p_izq = p_der + 2*direccion
				if p_izq < 0:
					p_izq = 0
			if direccion > 0:
				p_izq = p_in
				p_der = p_izq - 2*direccion
				if p_der < 0:
					p_der = 0
			motor1.start(p_der)
			motor2.start(p_izq)
except KeyboardInterrupt:
	motor1.stop()
	motor2.stop()
	GPIO.cleanup()

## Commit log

2017-03-23 Planos preeliminares que muestran una idea de las dimensiones aproximadas del diseño
    [Planos.dwg]
2017-04-13 Configuraciones de camara raspberrypi mediante la libreria python-picamera (la configuracion 1 ademas incluye la actualizacion de rasbian y la descarga de la libreria)
2017-04-25 adiccion diseno3D
    [Planos.dwg, Untitled.FCStd]
2017-04-28 adicion nuevos modelos 3D
    [Hull.FCStd, fancover.FCStd, raspbox.FCStd]
2017-05-09 Script para camara prueba
2017-05-09 modificacion del casco, montura de los motores y helices
    [Hull.FCStd, fancover.FCStd, motor_mount.FCStd]
2017-05-09 cambio de direccion de la montura de motor
    [motor_mount.FCStd]
2017-05-09 Preview de la camara
2017-05-09 Prueba 1 de pwm
2017-05-09 Fuckin' deleted the fuckin' folder, damn it
    [motor_mount.FCStd]
2017-05-10 finalizacion de la montura del motor y del casco
    [Hull.FCStd, motor_mount.FCStd]
2017-05-11 Gamepad module now accepts the nexts mapping formats; Circle = ( int(CircleAxe), int(CircleButton), int(CircleHat) ) LeftAnalogJoystick = ( (int(AxeX), int(AxeY), int(AxeZ), ...) , int(LAJButton) , i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
2017-05-13 se añaden los diseños definitivos y los archivos .stl con dimensiones inferiores a 200x200x200
    [Hull.FCStd, fancover.FCStd, fancover1.stl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]
2017-05-13 Prueba 2 del pwm
2017-05-13 Prueba 2 pwm corregido
2017-05-16 Changes done for supporting Extra cool Juan's Raspberry. Changes in pss for adhoc connection.
2017-05-16 Prueba motor 1 (introducimos valores de led(a) para variar el pwm)
2017-05-17 Camera record & RTSP connection trought VLC
2017-05-20 Handling pwm
2017-05-20 Test for pwm
2017-05-21 Added assembly model
    [asembly.FCStd]
2017-05-21 Prueba para ver si el motor se activa con el R2
2017-05-21 Control de los motores con R2 (motor derecho) y L2 (motor izquierdo)
2017-05-22 Minor changes
    [Untitled.FCStd]
2017-05-22 Added test for the main program (excluding pwm's relateds things)
2017-05-23 Cambio para prueba
2017-05-23 Otro cambio para la prueba
2017-05-23 PWM prueba de motor
2017-06-03 Son el par de comandos que permiten hacer streaming con la raspi una vez tiene instalado ffmpeg.
2017-06-03 Easy installing in Computer and Raspberry both side. Computer for decoding ans using ffplay. Raspberry for the streamming things.
2017-06-06 Pins that do not fail when doing pwm with them.
2017-06-06 Some useless code have been deleted. Bullshit Arduino Control have been added.
2017-06-30 actualización archivos finales
    [Hull.FCStd, asembly.FCStd, clip.FCStd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]
2018-10-16 Manual change of duty cycle in adafruit pwm
2018-10-17 Pwm board recives a 16 bit value hex (0-65535)
2018-10-21 Is it better to pwm esc eith 500hz?
